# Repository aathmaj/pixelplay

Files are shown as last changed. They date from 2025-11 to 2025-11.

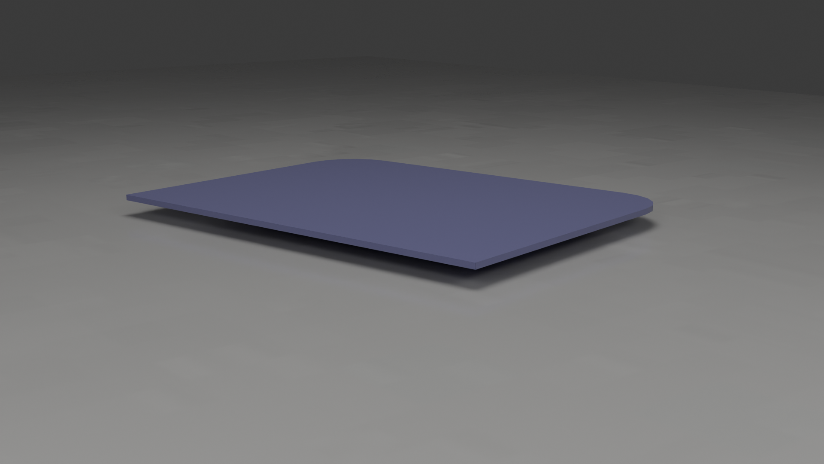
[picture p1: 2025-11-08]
assets/renders/0008.png

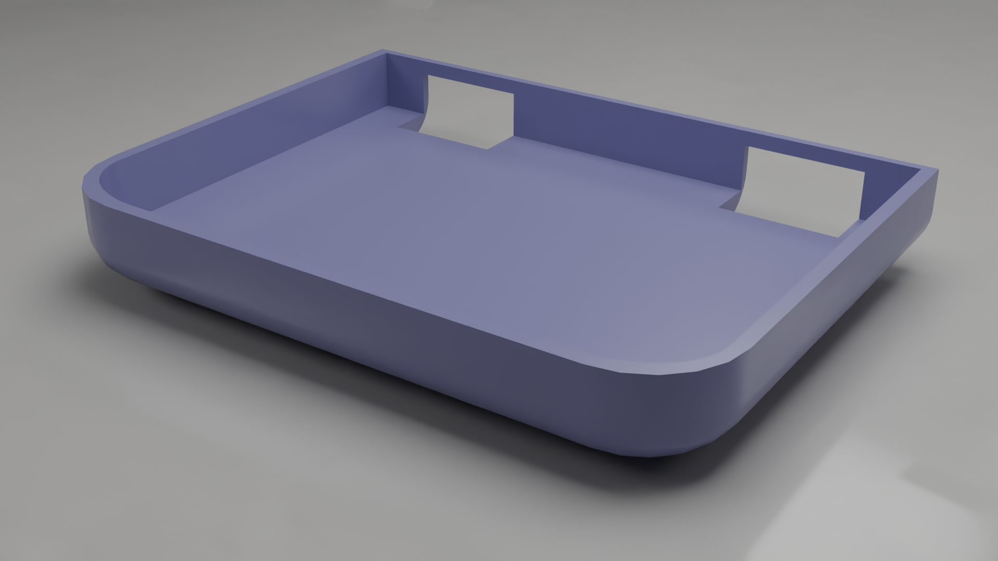
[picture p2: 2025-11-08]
assets/renders/0006.png

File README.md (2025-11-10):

# PixelPlay



## **A retro handheld with built in music playing capabilities!**

---

## About This Project

I absolutely love retro games and I absolutely love good music, but I dont have a handheld nor a music player I can use on the go, so I made this project. The PixelPlay is a complete handheld based off the GameBoy, which can both emulate GBA/SNES games, as well as play music through an audio jack. It is powered off a Raspberry Pi Zero 2 W.

---

##  Key Features

* The Brains: Raspberry Pi Zero 2W
* Firmware: Retropie
* Display: An 3.2in SPI TFT hat built for raspberryy pis.
* Audio: An I2S DAC system.
* Supports both wired headphones upto 128 ohm impedance and a built in speaker, using an amplifier and switching jack.
* Power Cicuit
    * TP4056 for micro USB charging.
    * DW01A + FS8205A for battery protection (over-discharge, short-circuit).
    * MT3608 boost converter to generate a stable 5V rail.
* Buttons: Includes D-Pad, A/B/X/Y, Start/Select, and two trigger pads.
* Custom Case: A 3D-printed enclosure that I designed in blender.

---

## Hardware: The Power Unit

### 1. Core Logic & Display
The Pi Zero 2 W is connected to the display hat, with wiring from the remaining GPIO pins to respective components.

### 2. Custom Power Circuit



Instead of an expensive module, the power system is built from individual ICs on the PCB.

* Micro USB ---> TP4056 ---> Battery
* Battery protected using the standard DW01A and FS8205A circuit
* Battery ---> MT3608
* MT3608 outputs a stable 5V
* 5V ---> RPi

### 3. Audio System
This is a high-fidelity 4-wire audio chain made using the CJMCU4344.
* DAC: The Pi's I2S pins are routed to the CJMCU-4344 (CS4344) module.
* Output: The CS4344 outputs a line-level signal that can drive headphones from 16-124 OHM impedances.
* Switching: This signal goes to the TIP and RING inputs of the switching headphone jack.
* Amplifier: The jack's TIP-SWITCH  and RING-SWITCH pins are wired to the input of a PAM8403 stereo amplifier.

**This results in a setup where the audio signals are routed to the inbuilt speaker when nothing is plugged into the switching jack, and when headphones are plugged in, direct output frm the I2S DAC**

### 4. Controls
* All 12 buttons are wired to a GPIO pin on one side and a common ground on the other. This is facilitated by the dpad and start-select buttons which have conductive strips on the bottom, which press on to a perfboard, completing a circuit to ground. The res of the buttons will be external hardware. The Pi's internal pull-up resistors are used.

---

## BILL OF MATERIALS

| Index | Manufacturer Part Number | Manufacturer Name | Description | Quantity | Part No on Site | Unit Price | Extended Price | Link |
| ----- | --- | --- | --- | --- | --- | --- | --- | --- |
| 1 | CC0805KKX7R9BB104 | YAGEO | CAP CER 0.1UF 250V X7T 0805 | 20 | ST2009SD0086 | 0.023 | $0.45 | [https://sharvielectronics.com/product/0-1uf-100nf-50v-capacitor-%c2%b110-tolerance-cc0805kkx7r9bb104-0805-package/](https://sharvielectronics.com/product/0-1uf-100nf-50v-capacitor-%C2%B110-tolerance-cc0805kkx7r9bb104-0805-package/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) |
| 2 | CC0805KKX7R8BB106 | YAGEO | CAP CER 10UF 25V X5R 0805 | 10 | ST2103SD2184 | 0.034 | $0.34 | [https://sharvielectronics.com/product/10uf-1000nf-25v-capacitor-%c2%b110-tolerance-cc0805kkx7r8bb106-0805-package/](https://sharvielectronics.com/product/10uf-1000nf-25v-capacitor-%C2%B110-tolerance-cc0805kkx7r8bb106-0805-package/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) |
| 3 | 1×11 2.54 Mm Berg Strip | \- | HEADER VERT 1x11 2.54MM | 1 | ST2136CO8090 | 0.056 | $0.06 | [https://sharvielectronics.com/product/11x1-11pin-male-square-straight-header-connector-11mm-height-2-54mm-pitch/](https://sharvielectronics.com/product/11x1-11pin-male-square-straight-header-connector-11mm-height-2-54mm-pitch/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) |
| 4 | 19-21/BHC-AN1P2/3T | Everlight | LED BLUE CLEAR CHIP SMD | 10 | ST2009SD0353 | 0.037 | $0.37 | [https://sharvielectronics.com/product/blue-smd-led-19-21-bhc-an1p2-3t-0603-package/](https://sharvielectronics.com/product/blue-smd-led-19-21-bhc-an1p2-3t-0603-package/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) |
| 5 | RC0603FR-071KL | YAGEO | RES SMD 1K OHM 0.1% 1/10W 0603 | 10 | ST2103SD1187 | 0.015 | $0.15 | [https://sharvielectronics.com/product/1k-ohm-1-10-watt-resistor-1-tolerance-rc0603fr-071kl-0603-package/](https://sharvielectronics.com/product/1k-ohm-1-10-watt-resistor-1-tolerance-rc0603fr-071kl-0603-package/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) |
| 6 | 0603SAF1201T5E | Royal Ohm | RES SMD 1.2K OHM 0.1% 1/10W 0603 | 20 | ST2009SD0388 | 0.0096 | $0.02 | [https://sharvielectronics.com/product/1-2k-ohm-1-10-watt-resistor-1-tolerance-0603saf1201t5e-0603-package/](https://sharvielectronics.com/product/1-2k-ohm-1-10-watt-resistor-1-tolerance-0603saf1201t5e-0603-package/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) |
| 7 | RC0402FR-07100RL | YAGEO | RES SMD 100 OHM 0.1% 1/16W 0402  | 20 | ST2103SD0837 | 0.0096 | $0.02 | [https://sharvielectronics.com/product/100-ohm-1-16-watt-smd-resistor-1-tolerance-rc0402fr-07100rl-0402-package/](https://sharvielectronics.com/product/100-ohm-1-16-watt-smd-resistor-1-tolerance-rc0402fr-07100rl-0402-package/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) |
| 8 | Micro 5.9ZB5.7 | SHOU HAN | CONN RCPT USB2.0 MICRO B SMD R/A | 1 | ST2103SD1926 | 0.14 | $0.14 | [https://sharvielectronics.com/product/micro-5-9zb5-7-micro-usb-2-0-b-type-right-angle-female-connector-5pin-smd-package/](https://sharvielectronics.com/product/micro-5-9zb5-7-micro-usb-2-0-b-type-right-angle-female-connector-5pin-smd-package/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) |
| 9 | 19-21/BHC-AN1P2/3T | Everlight | LED YELLOW CLEAR CHIP SMD | 10 | ST2009SD0353 | 0.037 | $0.37 | [https://sharvielectronics.com/product/blue-smd-led-19-21-bhc-an1p2-3t-0603-package/](https://sharvielectronics.com/product/blue-smd-led-19-21-bhc-an1p2-3t-0603-package/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) |
| 10 | TAJC226M006RNJ | KYOCERA AVX | CAP TANT POLY 22UF 16V CASEC | 5 | ST2103SD1014 | 0.12 | $0.60 | [https://sharvielectronics.com/product/22uf-6-3v-tantalum-capacitor-10-tolerance-tajc226m006rnj-case-c/](https://sharvielectronics.com/product/22uf-6-3v-tantalum-capacitor-10-tolerance-tajc226m006rnj-case-c/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) |
| 11 | B340A-E3/61T / B340A-E3/5AT | Vishay General Semiconductor | DIODE SCHOTTKY 40V 3A SMAF | 5 | ST2103SD1960 | 0.2 | $1.00 | [https://sharvielectronics.com/product/b340a-e3-61t-40v-3a-schottky-diode-do-214ac-package/](https://sharvielectronics.com/product/b340a-e3-61t-40v-3a-schottky-diode-do-214ac-package/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) |
| 12 | BWVS00505040220M00 | ZXCOMPO | FIXED IND 22UH 2A SMD | 1 | ST2103SD1152 | 1 | $1.00 | [https://sharvielectronics.com/product/nr6045-220-22uh-2-a-smd-inductor/](https://sharvielectronics.com/product/nr6045-220-22uh-2-a-smd-inductor/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) |
| 13 | CRCW060313K3FKEAC | Vishay | RES SMD 13.3K OHM 1% 1/10W 0603  | 20 | ST2103SD2348 | 0.008 | $0.16 | [https://sharvielectronics.com/product/13-3k-ohm-1-10-watt-resistor-1-tolerance-crcw060313k3fkeac-0603-package/](https://sharvielectronics.com/product/13-3k-ohm-1-10-watt-resistor-1-tolerance-crcw060313k3fkeac-0603-package/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) |
| 14 | 3362P-1-104LF | Bourns Inc. | TRIMMER 100KOHM 0.5W PC PIN SIDE | 1 | ST2136CO6475 | 0.2 | $0.20 | [https://sharvielectronics.com/product/100k-ohm-500mw-single-turn-cermet-trimmer-potentiometer-3362p-1-104-through-hole/](https://sharvielectronics.com/product/100k-ohm-500mw-single-turn-cermet-trimmer-potentiometer-3362p-1-104-through-hole/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) |
| 15 | FS8205A | \- | MOSFET 20V 6A | 5 | ST2103SD0926 | 0.07400 | $0.47 | [https://sharvielectronics.com/product/fs8205a-dual-n-channel-power-mosfet-lithium-battery-protection-sot23-6-package/](https://sharvielectronics.com/product/fs8205a-dual-n-channel-power-mosfet-lithium-battery-protection-sot23-6-package/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) |
| 16 | TP4056 | \- | LINEAR CHARGER | 1 | ST2103SD2342 | 0.07400 | $0.10 | [https://sharvielectronics.com/product/tp4056-4-2v-1a-standalone-linear-li-lon-battery-charger-esop-8-package/](https://sharvielectronics.com/product/tp4056-4-2v-1a-standalone-linear-li-lon-battery-charger-esop-8-package/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) |
| 17 | DW01A | \- | PROTECTION IC | 1 | ST2103SD0927 | 0.09900 | $0.10 | [https://sharvielectronics.com/product/dw01a-lithium-battery-protection-ic-sot23-6/](https://sharvielectronics.com/product/dw01a-lithium-battery-protection-ic-sot23-6/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) |
| 18 | MT3608 | \- | STEP UP CONVERTER | 1 | ST2103SD0818 | 0.15000 | $0.15 | [https://sharvielectronics.com/product/mt3608-high-efficiency-1-2mhz-2a-step-up-converter-sot23-6-package/](https://sharvielectronics.com/product/mt3608-high-efficiency-1-2mhz-2a-step-up-converter-sot23-6-package/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) |
| 19 | Raspberry Pi Zero 2 W | Raspberry Pi | \- | 1 | ST2001DV0171 | 18.2300 | $18.23 | [https://sharvielectronics.com/product/raspberry-pi-zero-2-w/](https://sharvielectronics.com/product/raspberry-pi-zero-2-w/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) |
| 20 | 20 x 2 PIN HEADER | \- | FEMALE PIN HEADER 2X2 | 1 | ST2136CO7815 | 0.65000 | $0.65 | [https://sharvielectronics.com/product/2x20-pin-23-5mm-long-straight-female-berg-strip-2-54mm-pitch/](https://sharvielectronics.com/product/2x20-pin-23-5mm-long-straight-female-berg-strip-2-54mm-pitch/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) |
| 21 | JST CONNECTOR | \- | JST CONNECTOR 30CM | 1 | ST2136CO8727 | 0.10000 | $0.10 | [https://sharvielectronics.com/product/jst-ph-2-2-pin-double-sided-female-to-female-connector-with-2mm-pitch-30cm-wire-length/](https://sharvielectronics.com/product/jst-ph-2-2-pin-double-sided-female-to-female-connector-with-2mm-pitch-30cm-wire-length/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) |
| 22 | PAM8403 | \- | STEREO AMPLIFIER | 1 | ST2001SM0083 | 0.30000 | $0.30 | [https://sharvielectronics.com/product/pam8403-5v-2-channel-stereo-audio-amplifier-module/](https://sharvielectronics.com/product/pam8403-5v-2-channel-stereo-audio-amplifier-module/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) |
| 23 | 3.25in TFT | \- | RPI | 1 | ST2001SM0288 | 12.5000 | $12.50 | [https://sharvielectronics.com/product/3-5-inch-tft-lcd-touch-display/](https://sharvielectronics.com/product/3-5-inch-tft-lcd-touch-display/) |
| 24 | Single Sided Universal PCB Prototype Board – 20×30 cm | \- | PERFBOARD PCB PROTOTYPE BOARD | 1 | ST2106CO4011 | 4.3900 | $4.39 | [https://sharvielectronics.com/product/single-sided-universal-pcb-prototype-board-20x30-cm/](https://sharvielectronics.com/product/single-sided-universal-pcb-prototype-board-20x30-cm/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) |
| 25 | 3.5mm Female Stereo Audio Socket Headphone Jack Connector 5 Pin PCB Mount | \- | FEMALE AUDIO JACK SWITCHING | 1 | ST2006CO0034 | 0.11000 | $0.11 | [https://sharvielectronics.com/product/3-5mm-female-stereo-audio-socket-headphone-jack-connector-5-pin-pcb-mount/](https://sharvielectronics.com/product/3-5mm-female-stereo-audio-socket-headphone-jack-connector-5-pin-pcb-mount/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) |
| 26 | 8 Ohm 1 Watt Magnet Speaker 36mm Diameter With 2Pin Connector | \- | SPEAKER 1W TOP PORT 9 | 1 | ST2136CO7965 | 0.68000 | $0.68 | [https://sharvielectronics.com/product/8-ohm-1-watt-magnet-speaker-36mm-diameter-with-2pin-connector/](https://sharvielectronics.com/product/8-ohm-1-watt-magnet-speaker-36mm-diameter-with-2pin-connector/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) |
| 27 | Lipo Rechargeable Battery LP88426B | \- | Battery-3.7V/3300mAH | 1 | ST2001BY0284 | 4.75 | $5.00 | [https://sharvielectronics.com/product/lipo-rechargeable-battery-3-7v-3300mah-lp88426b/](https://sharvielectronics.com/product/lipo-rechargeable-battery-3-7v-3300mah-lp88426b/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) |
| 28 | SS12F44 | \- | 3 Pin Slide Switch | 5 | ST2136CO8564 | 0.072 | $0.36 | [https://sharvielectronics.com/product/ss12f44-3pin-spdt-slide-switch-with-single-row-vertical-pcb-mountable-3mm-pitch/](https://sharvielectronics.com/product/ss12f44-3pin-spdt-slide-switch-with-single-row-vertical-pcb-mountable-3mm-pitch/) |
| 29 | CJMCU-4344 CS4344 | | I2S DAC | 1 | ST2010SM1643 | 2.22 | $2.22 | [https://sharvielectronics.com/product/cjmcu-4344-cs4344-digital-to-analog-stereo-audio-conversion-module/](https://sharvielectronics.com/product/cjmcu-4344-cs4344-digital-to-analog-stereo-audio-conversion-module/) |
| | GST | | | | | | $10.00 | |
| | PCB | LION CIRCUITS | | | | | $10.64 | |
| | 3D PRINT(SHIPPING) | PRINTING LEGION | | | | | $6.00 | |
| | | | | | TOTAL | | $76.88 | |

## CART SCREENSHOTS:
 **Sharvi Electronics**






**Lion Circuits**



## CASE:








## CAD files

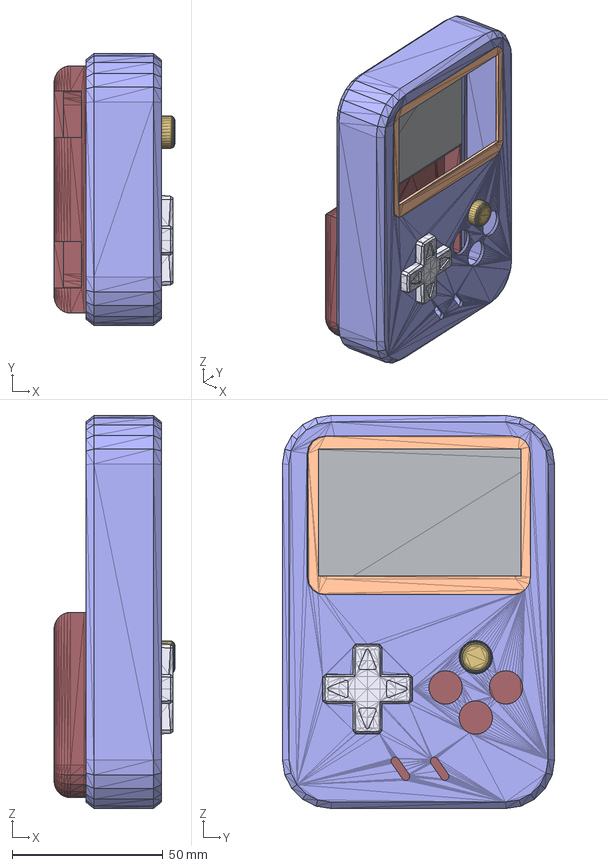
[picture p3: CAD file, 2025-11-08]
pixelplay.step
40.1 x 90.2 x 130.3 mm
ABXYsc001 (Solid)
backplatesc001 (Solid)
basesc001 (Solid)
bezelsc001 (Solid)
body001 (Solid)
dpad001 (Solid)

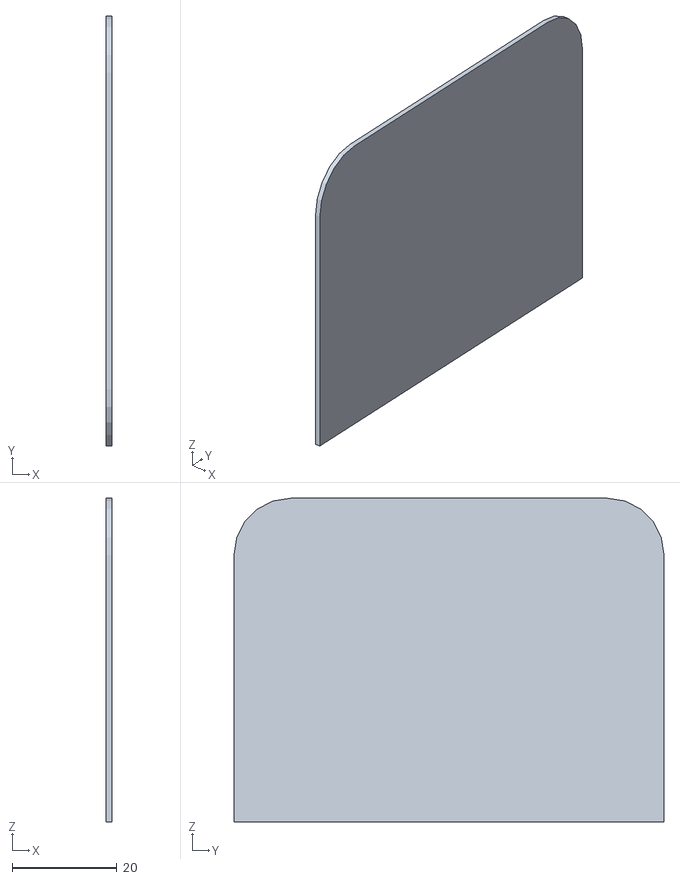
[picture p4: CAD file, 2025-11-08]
stl/backplatesc.stl
1.06 x 82.0 x 61.7

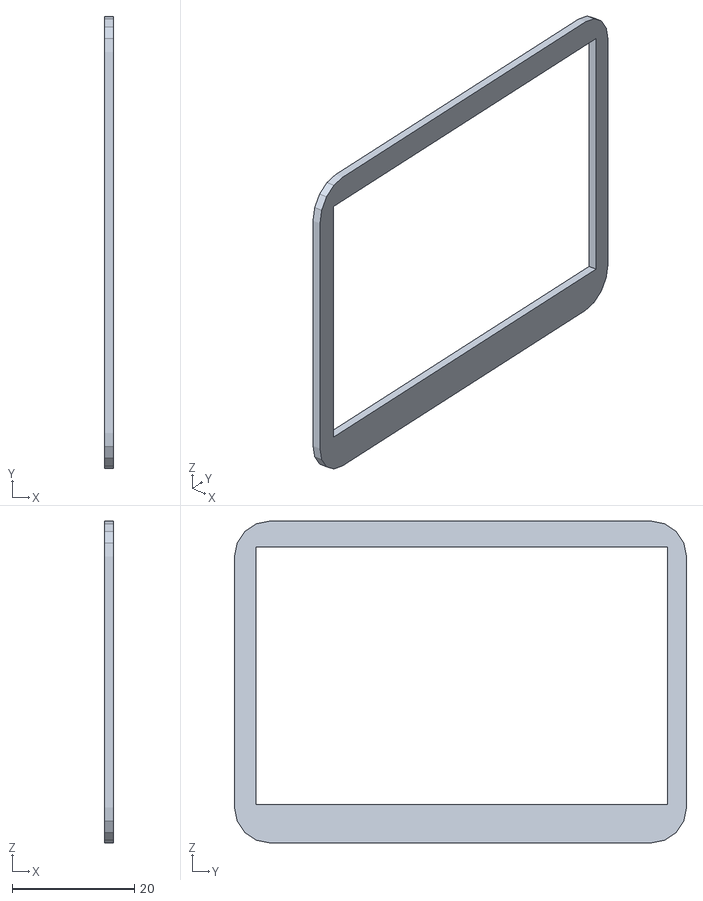
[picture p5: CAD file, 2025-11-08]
stl/bezelsc.stl
1.40 x 73.8 x 52.6

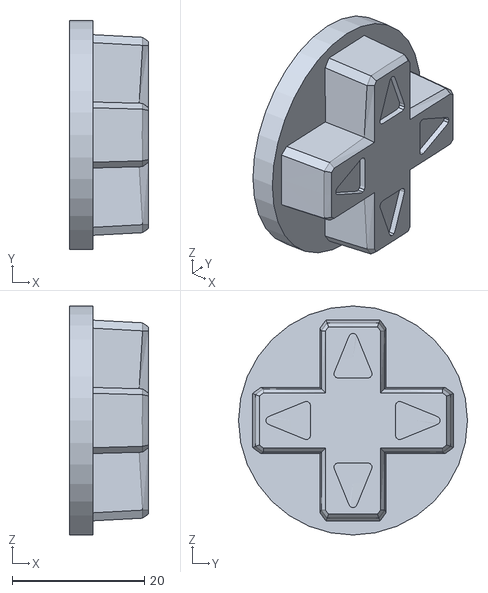
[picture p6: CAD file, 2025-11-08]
stl/dpad.stl
11.9 x 34.6 x 34.6

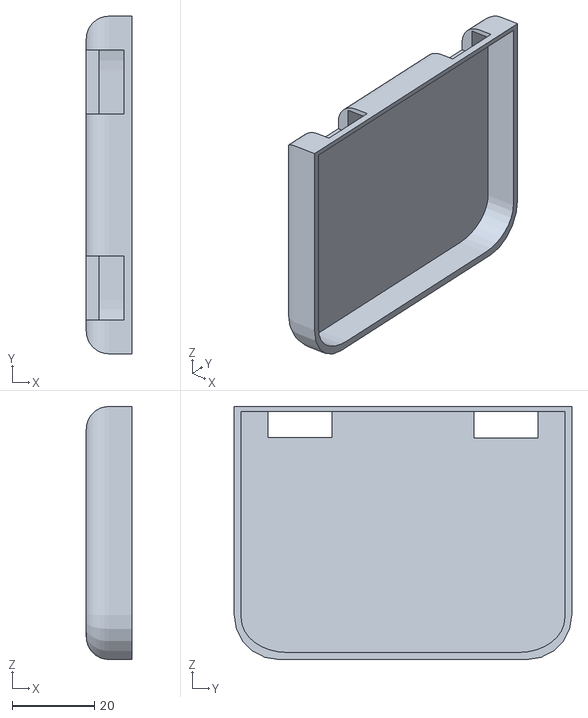
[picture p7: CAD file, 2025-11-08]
stl/basesc.stl
11.1 x 82.0 x 61.5

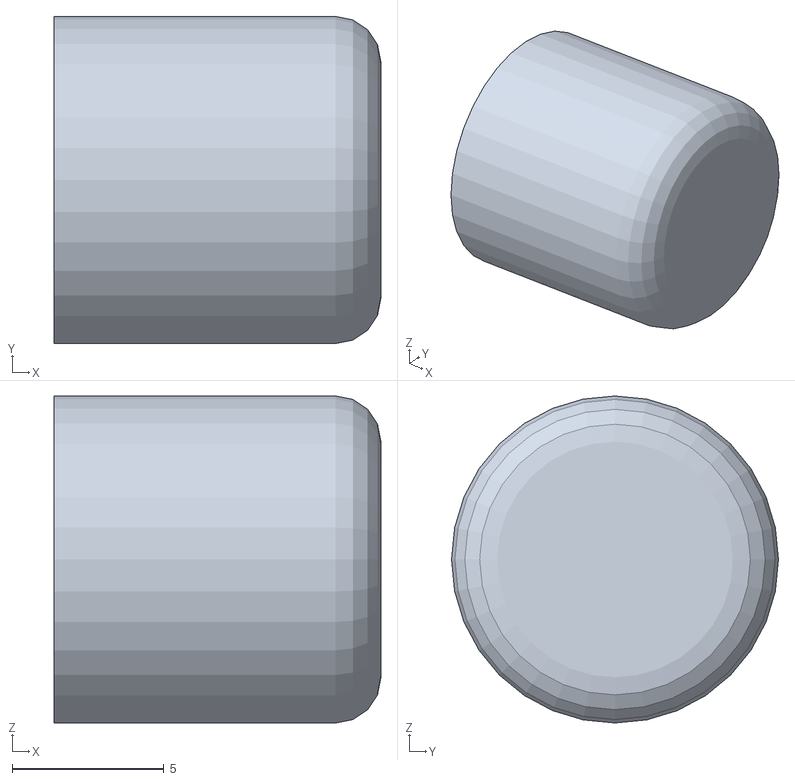
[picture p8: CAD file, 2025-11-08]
stl/ABXYsc.stl
10.8 x 10.8 x 10.8

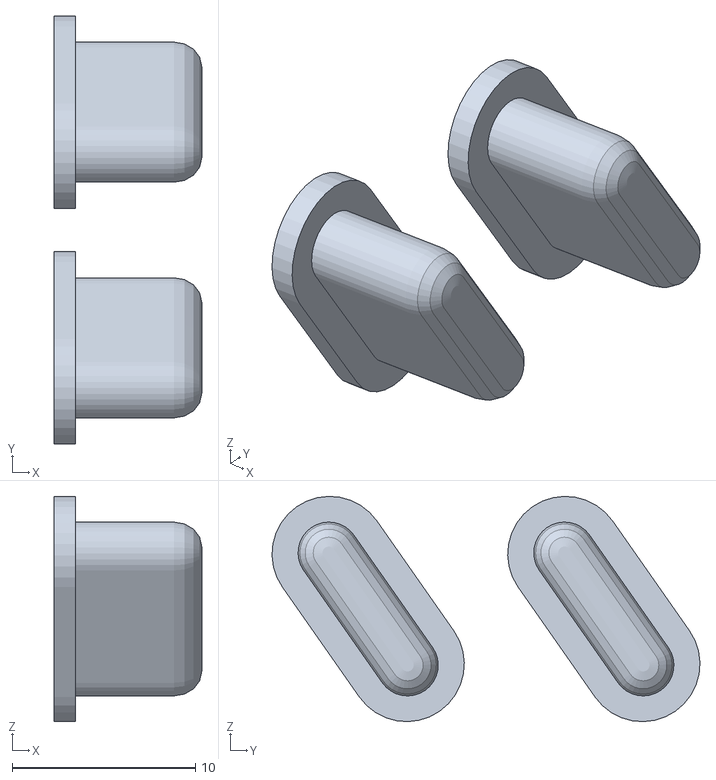
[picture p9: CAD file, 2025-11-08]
stl/start_select.stl
8.06 x 23.4 x 12.3

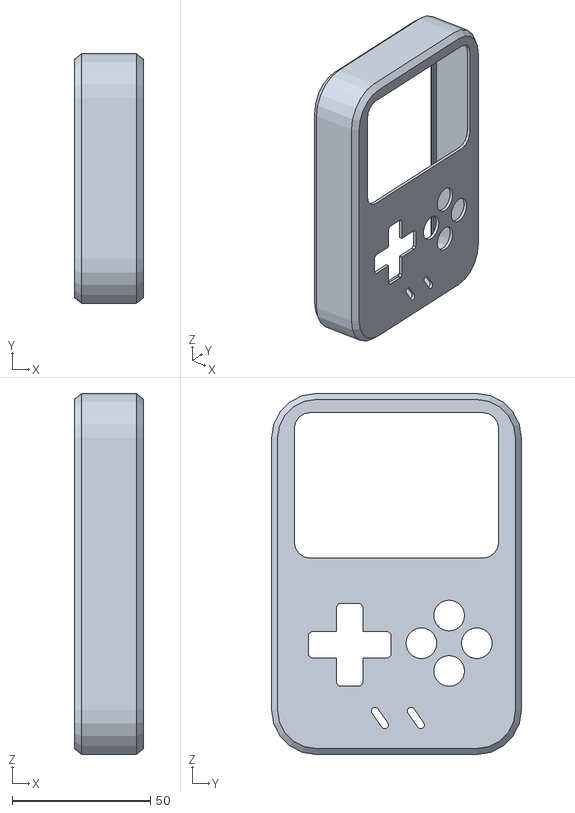
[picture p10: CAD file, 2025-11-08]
stl/body.stl
25.1 x 90.2 x 130.3

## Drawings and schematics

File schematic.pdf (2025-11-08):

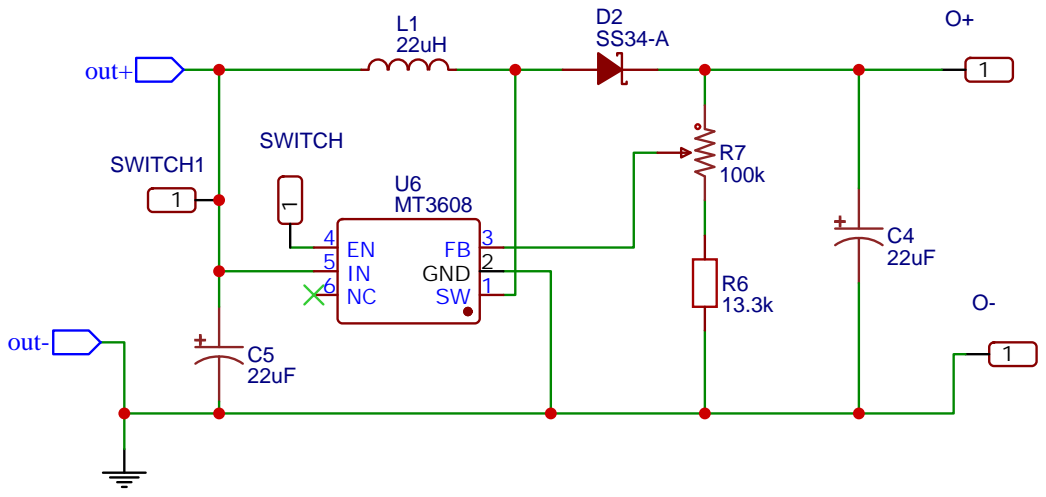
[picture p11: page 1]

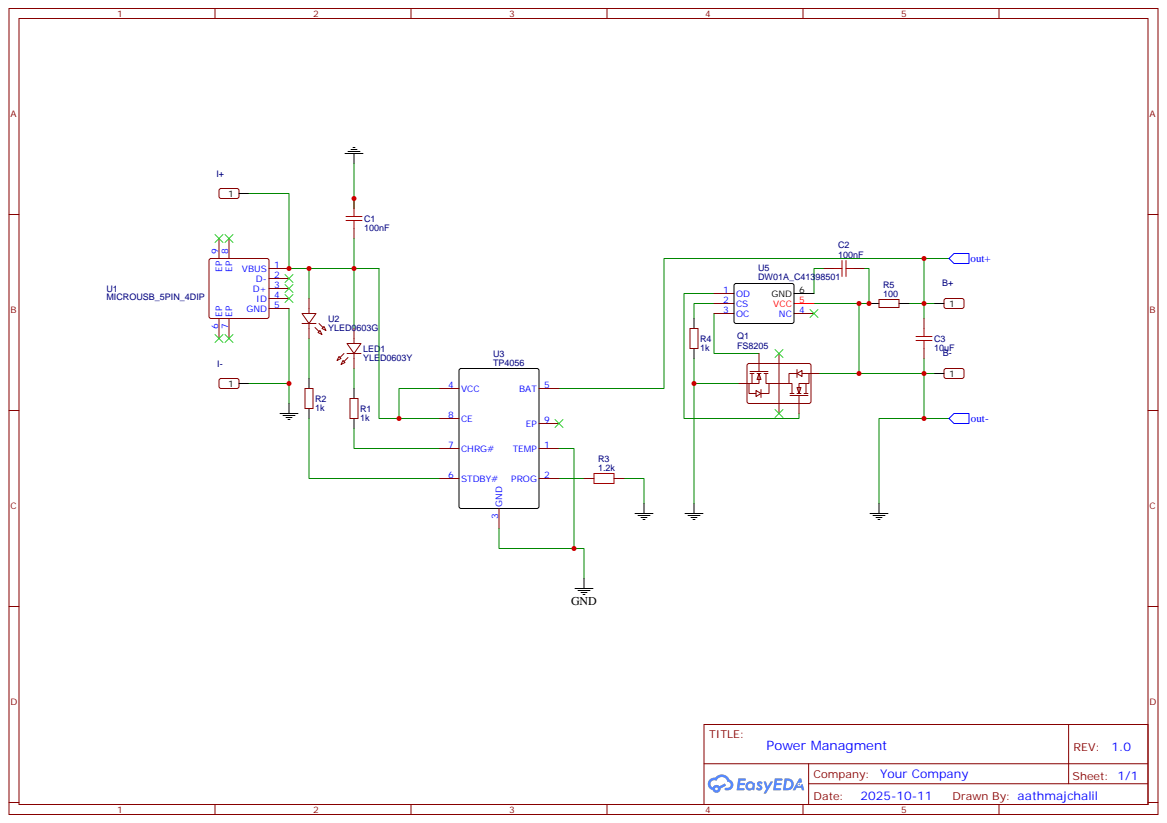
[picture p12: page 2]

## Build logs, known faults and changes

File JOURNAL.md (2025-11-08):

<!--
  ===================    !!READ THIS NOTICE!!   ====================
  DO NOT edit this file manually. Your changes WILL BE OVERWRITTEN!
  This journal is auto generated and updated by Hack Club Blueprint.
  To edit this file, please edit your journal entries on Blueprint.
  ==================================================================

  ~17 HOURS TAKEN
-->

## 10/10/2025 - Reasearch and basic concept made. Parts planned out.   

Screenshot 2025-10-10 202001.png

Finally finished the first part of the research and planning. I've settled on building this thing around a Raspberry Pi Zero 2W....kinda like that other fidelity project i was planning on.

### **THE MASTER PLAN** 

**CORE**
It's all based around the Raspberry Pi Zero 2W which will handle all the processing for both gaming and music. The entire power system is built around it, with USB-C for easy charging.

**UI**
It’s got a bright, landscape color TFT screen for all the visuals. For controls, there's a full set of gaming buttons: a D-Pad, A/B/X/Y, plus Start and Select. To make it feel premium, im adding HAPTIC!

**MEDIA AND STORAGE**
A high-quality I2S digital audio system will drive both a built-in speaker and a headphone jack (maybe bluetooth too). All the games and music will be loaded from a microSD card slot.

## 10/11/2025 - Updates  

Made new updates:



We are going to add triggers on the back of the console, right on top of where the battery will be placed as you can see in the crude diagram I have attached above. We will also be adding features to spport using a dock in the future, kinda like the nintendo switch. 

Also finalised base hardware and bom.  

## 10/12/2025 - Mockup and basic battery and circuit protection circuit made  

### Mockup and Battery Protection

Finished a basic mockup which ill be basing the project on. I've made my battery protection circuit using DW01A and FS8205A boards.

I used blender to make a quick mockup of how i want the project to look...



The DW01A is a battery protection IC and the FS8205A acts as an efficient switch to protect against overcurrent by switching power paths.



## 10/17/2025 - Fixed errors and routed pcb  

I just realised the circuit in the other photo wasnt completely refined so i went ahead and fixed it. I finished routing the PCB.



This PCB will serve as the main battery protection circuit, which I have decided to leave as seperate module. Next step of the process will be making the I2S DAC circuit.

## 10/19/2025 - Completed 5V boost controller schematic  

I completed the schematic for the voltage boost controller circuit. It uses the MT3608, which is a small frequency step up converter.

I started with the MT3608 and built the circuit using thestandard parts for the circuit. Ive also added a trimmer potentiometer so that I can set the output voltage to any value up to 28 V for further applications.

Most of the time spent on the project is research into how ill be making the circuit.



Ive also completed base research into how ill be making the next part, the I2S DAC circuit.

## 10/20/2025 - Made some changes and routed PCB  

I found a fatal design flaw, where if Icranked up the resistor to 100k ohm it would fry the MT3608. Fixed it, also changed the design to use polarized tantalum capacitors which have a low ESR, unlike normal electrolytic capacitors.

Here is the schematic: 

I also finished routing the pcb, which took around 30 mins as it was rather simple wih only a few components. What took up most of the time was doing research for the required trace thickness I would require for the best possible results.

Here is the routing:


## 10/24/2025 - Combined both PCBs for an integrated circuit. Routed PCB  

Decided to switch to a PCB that has both the boost IC and power protection circuit to save costs on PCB manufacturing. Added net ports and finished routing. Came across a problem due to trace widths which I fixed using 0.6 as the min track width. I also positioned the pins strategically for the entire project. Also added gnd pours. 


## 10/26/2025 - Made BOM (excluding 3d prints)  

I made the bill of materials for the project as I have completed the core of the project. All that is now left is making the case and buttons.

[CLICK FOR BOM](/user-attachments/blobs/proxy/eyJfcmFpbHMiOnsiZGF0YSI6NTc0NCwicHVyIjoiYmxvYl9pZCJ9fQ==--6ad8c8fefc4a8e7eb8322191a9bfb185391957a7/Unnamed%20List(1)%20-%20My%20Lists%20Worksheet.csv)

_BOM is bound to changes as desired by me (with proper reasons of course)_

Most of the time taken was due to most of the parts I used while making the PCB not being avaliable. I had to find alternatives and source better/cheaper parts. The current total is $53.5 excluding shipping and taxes. 

The next part of the project will be making the case and buttons. The plan is to make buttons which have a conductive surface on the bottom which will hit a perfboard ill make so that itll trigger the button commands with the GPIO pins being connected to GND.  

## 10/29/2025 - Made case   

I made the case/housing. Its basic with 4 parts:

- Front Cover (the top which includes all button holes.)
- Backplate (a plate behind the screen to cover the back)
- Back cover (bottom/back with trigger holes(also supports the battery and rpi)
- A border for the screen



I will finish the button designs soon with the dpad, volume and trigger buttons. I will also position the port hole on the case.

## 11/7/2025 - Completed project  

I fixed all issues, completed sourcing the parts and also finished the 3d models. 

I also updated the pcb to house a different 22uH inductor, as I couldnt find the original one for cheap on sharvielecronics.


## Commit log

2025-11-07 Revise project description and add bill of materials
    Updated wording for clarity and added a bill of materials section with detailed component information.
2025-11-08 added case img
2025-11-08 added stls
    [ABXYsc.stl, backplatesc.stl, basesc.stl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]
2025-11-08 added schematic and pickandplace files
    [pickandplace.csv]
2025-11-08 pcb pic
2025-11-08 added step
    [pixelplay.step]
2025-11-09 Update bom.csv with new parts and prices
    [bom.csv]
